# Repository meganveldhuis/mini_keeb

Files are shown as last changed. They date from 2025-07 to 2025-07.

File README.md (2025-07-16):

# Mini Keeb

## Hardware

### Components

- 16 Cherry MX Switches
- 2 rotary encoders
- 1 128x64 OLED (0.96")

### Schematic

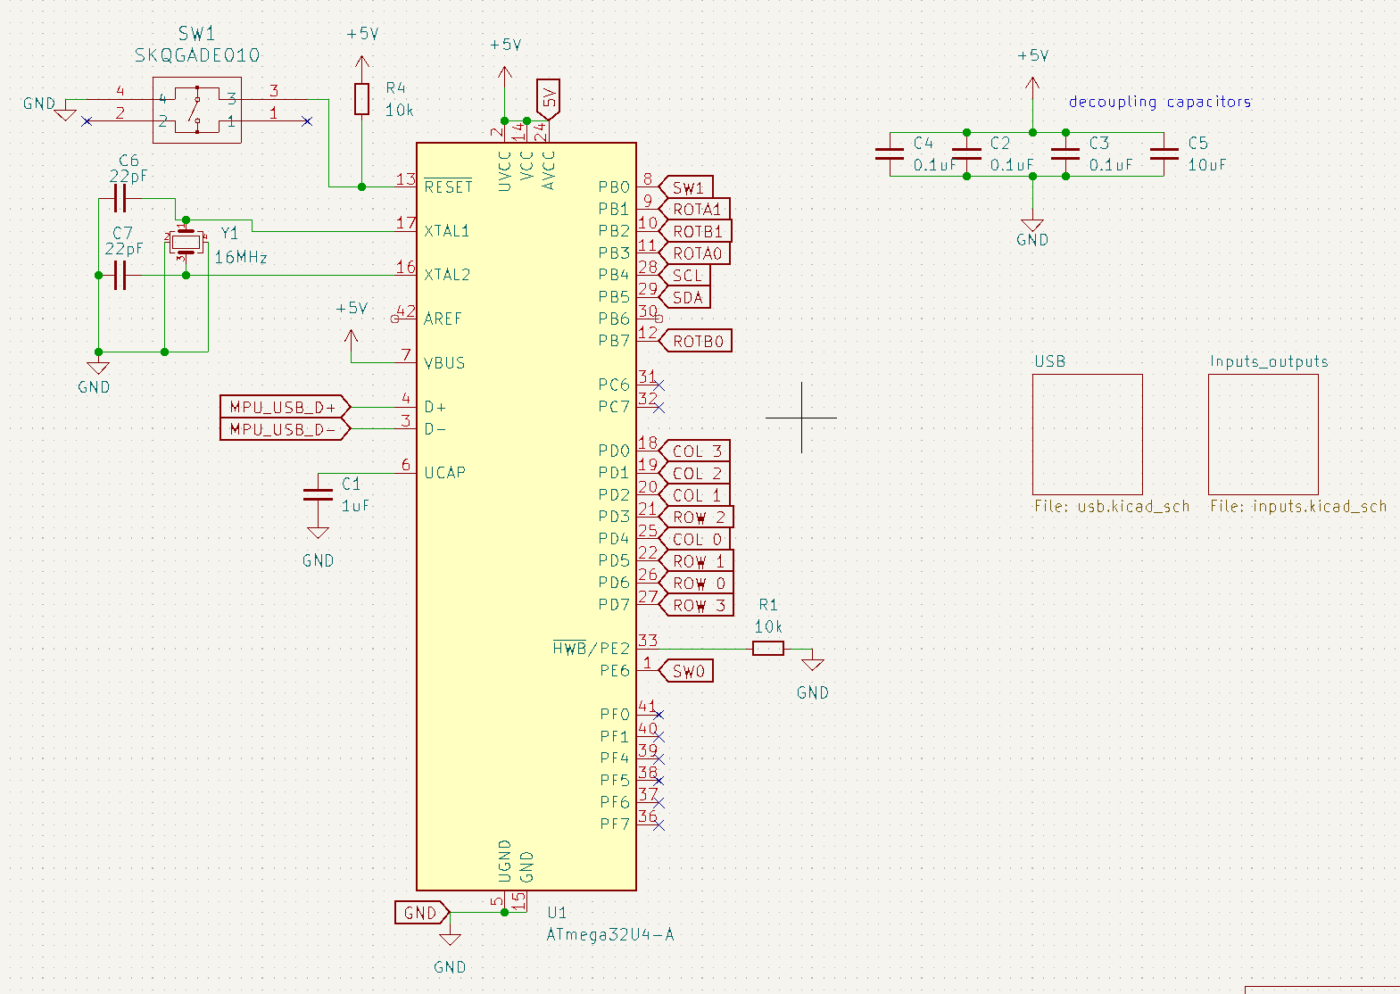
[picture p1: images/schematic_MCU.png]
Schematic of the ATMega32U4 and its connections


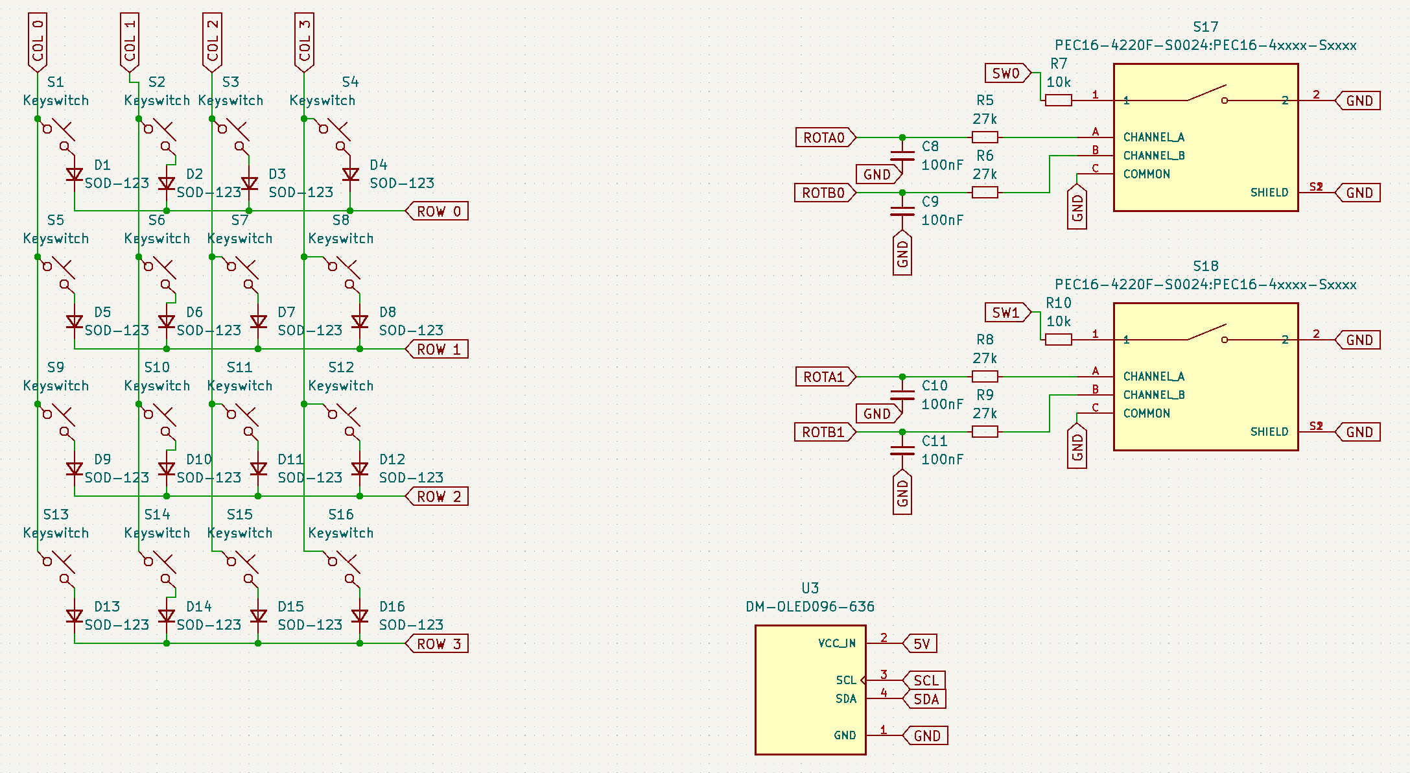
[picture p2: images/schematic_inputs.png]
Schematic of inputs and outputs (switches, rotary encoders, OLED)


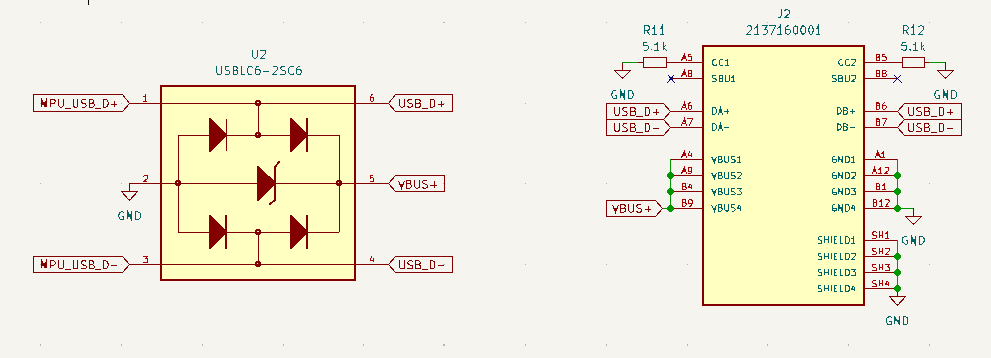
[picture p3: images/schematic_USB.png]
Schematic of USBC connection


### PCB

( slightly outdated screenshots )
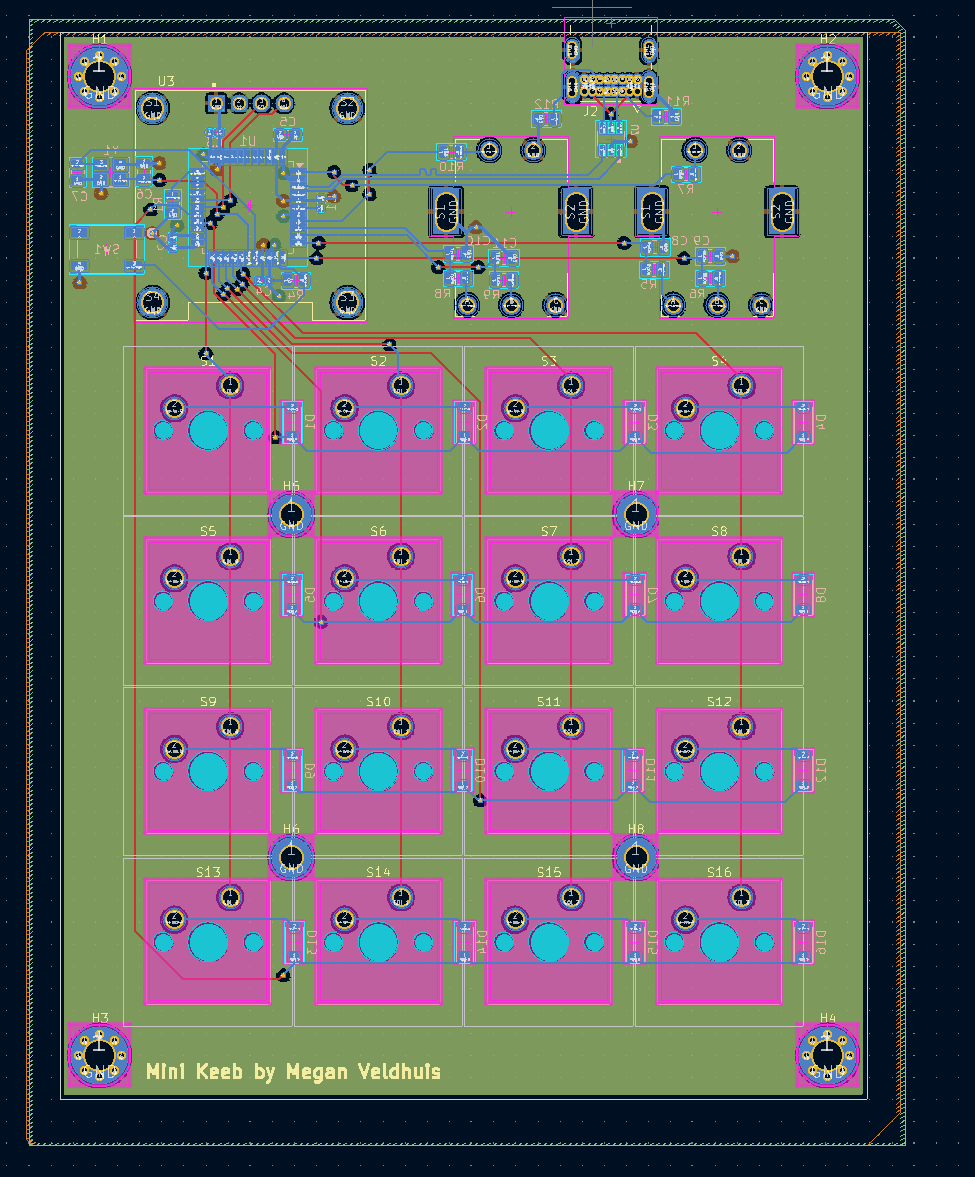
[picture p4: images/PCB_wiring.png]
Screenshot of PCB routing diagram


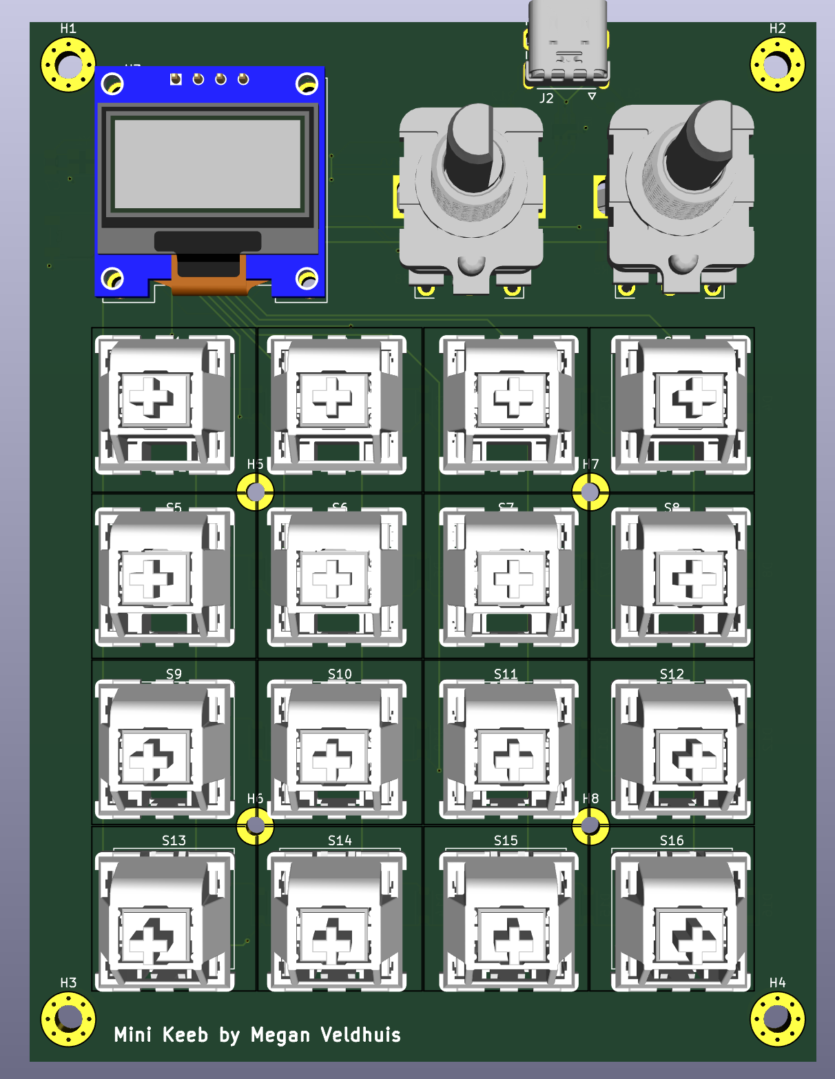
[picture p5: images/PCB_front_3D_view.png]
Screenshot of the front of the PCB, showing the keys, OLED, and rotary encoders


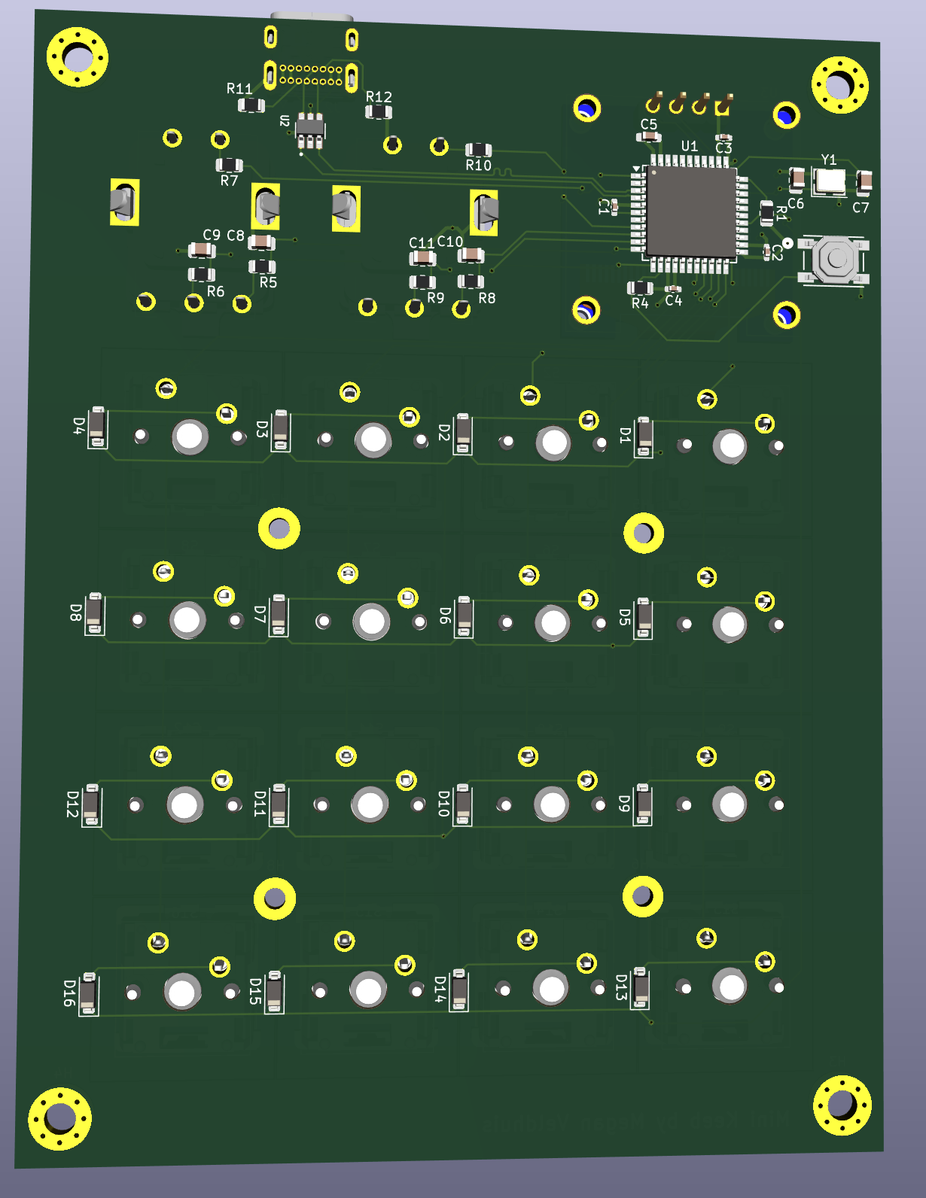
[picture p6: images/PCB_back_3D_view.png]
Screenshot of the back of the PCB


## Software

coming soon

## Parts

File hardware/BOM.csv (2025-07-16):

 |  | PART | AMT |  | PRICE per unit | PART PRICE | LINK
TRUE | D1, D2, D3, D4, D5, D6, D7, D8, D9, D10,D11, D12, D13, D14, D15, D16 | SOD123 Diode | 16 | 160 | $0.15 | $2.40 | https://www.digikey.ca/en/products/detail/diodes-incorporated/BAV21W-7-F/717710
TRUE | S17, S18 | PEC16 rot encoder | 2 | 20 | $3.15 | $6.30 | https://www.digikey.ca/en/products/detail/bourns-inc/PEC16-4220F-S0024/3534239 | https://www.digikey.ca/en/products/detail/bourns-inc/PEC16-4220F-S0012/3780232
TRUE | S1-S16 | MX Switches | 16 | 160 |  | $0.00
TRUE | C1 | 1uF cap (0402) | 1 | 10 | $0.12 | $0.12 | https://www.digikey.ca/en/products/detail/taiyo-yuden/JMK105BJ105KV-F/930583
TRUE | C2, C3, C4 | 0.1uF cap (0402) | 3 | 30 | $0.12 | $0.36 | https://www.digikey.ca/en/products/detail/samsung-electro-mechanics/CL05B104KP5NNNC/3886660
TRUE | C5 | 10uF cap (0603) | 1 | 10 | $0.21 | $0.21 | https://www.digikey.ca/en/products/detail/murata-electronics/GRM21BR61C106KE15K/2546903
TRUE | C6, C7 | 22pF cap (0805) | 2 | 20 | $0.15 | $0.30 | https://www.digikey.ca/en/products/detail/kemet/C0805C220J5GACTU/411112
TRUE | C8, C9, C10, C11 | 100nF cap (0805) | 4 | 40 | $0.47 | $1.88 | https://www.digikey.ca/en/products/detail/vishay-sprague/TMCP1D104MTRF/10107432
TRUE | U3 | OLED 128x64 (0.96") | 1 | 10 | $12.00 | $12.00 | https://www.amazon.ca/128X64-Serial-Display-Module-White/dp/B075H4CSXF?sp_csd=d2lkZ2V0TmFtZT1zcF9hdGY | https://www.digikey.ca/en/products/detail/adafruit-industries-llc/326/5353680
TRUE | R1, R4, R7, R10 | 10k resistor (0805) | 4 | 40 | $0.16 | $0.64 | https://www.digikey.ca/en/products/detail/susumu/RR1220P-103-D/432315
TRUE | R5, R6, R8, R9 | 27k resistor (0805) | 4 | 40 | $0.16 | $0.64 | https://www.digikey.ca/en/products/detail/stackpole-electronics-inc/RMCF0805JT27K0/1757886
FALSE | SW1 | low-profile switch | 1 | 10 | $0.31 | $0.31 | https://www.digikey.ca/en/products/detail/alps-alpine/SKQGADE010/18109115
TRUE | U1 | ATMega32U4-A | 1 | 10 | $8.30 | $8.30 | https://www.digikey.ca/en/products/detail/microchip-technology/ATMEGA32U4-AU/1914602
FALSE | J2 | USB-C connector (Molex-2137160001) | 1 | 10 | $2.12 | $2.12 | https://www.digikey.ca/en/products/detail/molex/2137160001/13662558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
TRUE | Y1 | 16MHz crystal (SMD 3225-4pin) | 1 | 10 | $0.61 | $0.61 | https://www.digikey.ca/en/products/detail/epson/TSX-3225-16-0000MF09Z-AC0/5260850
FALSE | U2 | USBLC6-2SC6 | 1 | 10 | $0.36 | $0.36 | https://www.digikey.ca/en/products/detail/stmicroelectronics/USBLC6-2SC6/1040559
 |  |  |  |  | TOTAL | 34.46

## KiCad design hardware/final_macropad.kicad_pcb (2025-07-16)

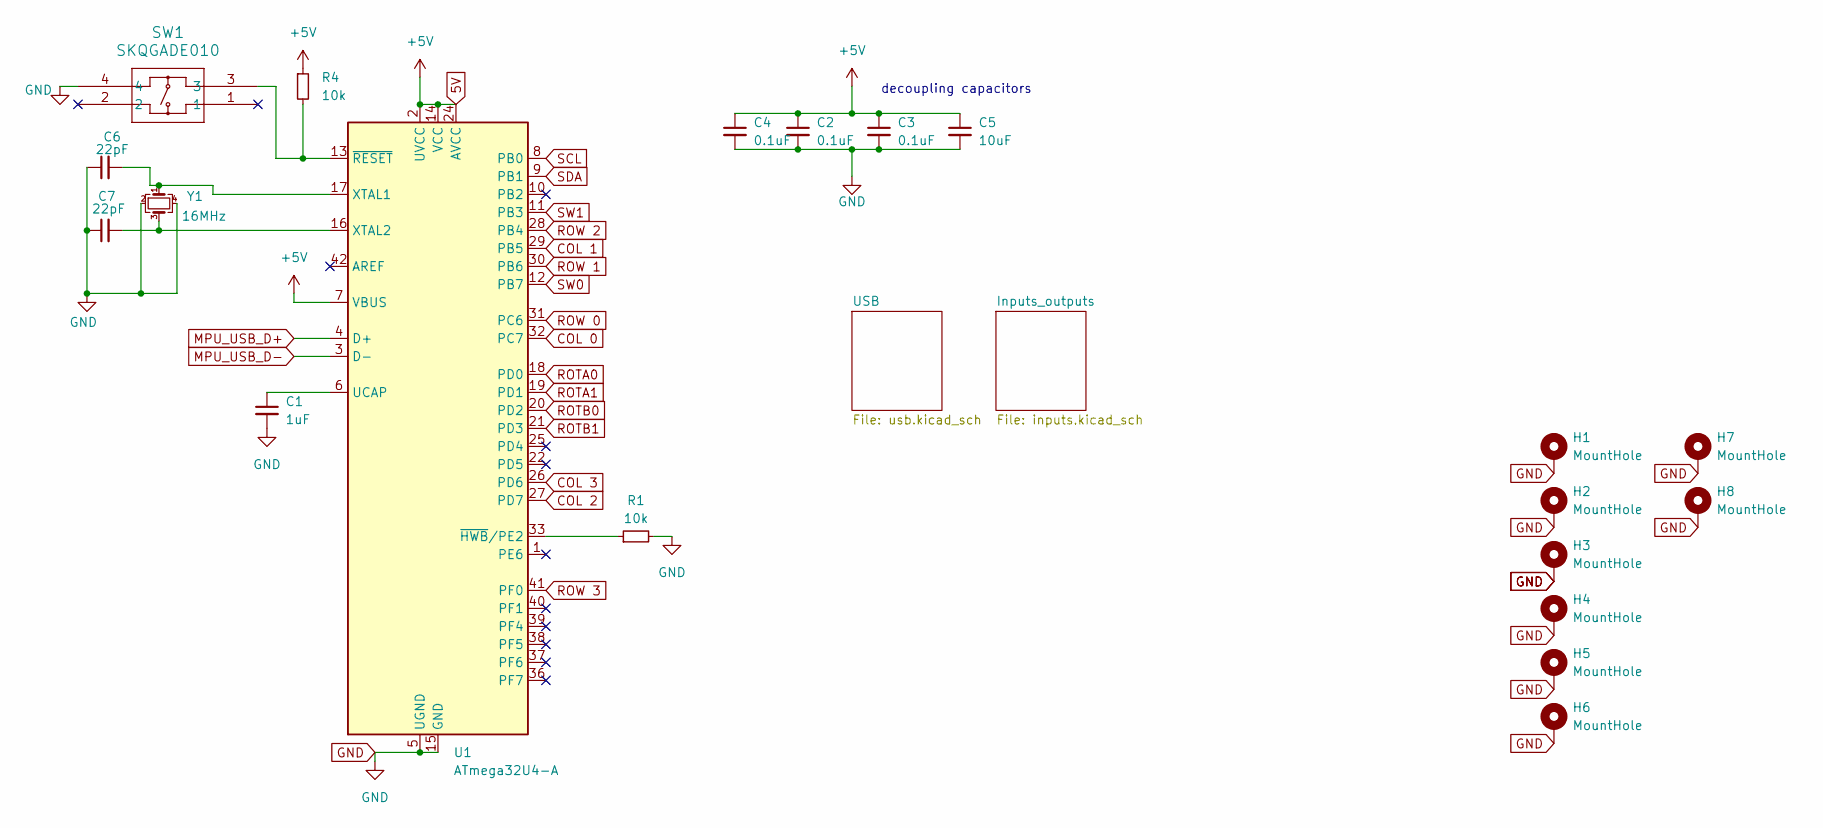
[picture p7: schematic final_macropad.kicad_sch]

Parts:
C1: 1uF; C_0402_1005Metric_Pad0.74x0.62mm_HandSolder
C2, C3, C4: 0.1uF; C_0402_1005Metric_Pad0.74x0.62mm_HandSolder
C5: 10uF; C_0603_1608Metric_Pad1.08x0.95mm_HandSolder
C6, C7: 22pF; C_0805_2012Metric
H1, H2, H3, H4: MountHole; MountingHole_3.2mm_M3_Pad_Via
H5, H6, H7, H8: MountHole; MountingHole_2.2mm_M2_Pad
R1, R4: 10k; R_0805_2012Metric
SW1: SKQGADE010; SKQGADE010_AAL
U1: ATmega32U4-A; TQFP-44_10x10mm_P0.8mm
Y1: 16MHz; Crystal_SMD_3225-4Pin_3.2x2.5mm

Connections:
5V: C2.1, C3.1, C4.1, C5.1, R4.1, U1.2 (UVCC), U1.7 (VBUS), U1.14 (VCC), U1.24 (AVCC), U1.34 (VCC), U1.44 (AVCC); also elsewhere on the board
COL 0: U1.32 (PC7); also elsewhere on the board
COL 1: U1.29 (PB5); also elsewhere on the board
COL 2: U1.27 (PD7); also elsewhere on the board
COL 3: U1.26 (PD6); also elsewhere on the board
GND: C1.2, C2.2, C3.2, C4.2, C5.2, C6.1, C7.1, H1.1, H2.1, H3.1, H4.1, H5.1, H6.1, H7.1, H8.1, R1.2, SW1.4, U1.5 (UGND), U1.15 (GND), U1.23 (GND), U1.35 (GND), U1.43 (GND), Y1.2, Y1.4; also elsewhere on the board
MPU_USB_D+: U1.4 (D+); also elsewhere on the board
MPU_USB_D-: U1.3 (D-); also elsewhere on the board
unnamed: C1.1, U1.6 (UCAP)
unnamed: C6.2, U1.17 (XTAL1), Y1.1
unnamed: C7.2, U1.16 (XTAL2), Y1.3
unnamed: R1.1, U1.33 (~HWB/PE2)
unnamed: R4.2, SW1.3, U1.13 (~RESET)
ROTA0: U1.18 (PD0); also elsewhere on the board
ROTA1: U1.19 (PD1); also elsewhere on the board
ROTB0: U1.20 (PD2); also elsewhere on the board
ROTB1: U1.21 (PD3); also elsewhere on the board
ROW 0: U1.31 (PC6); also elsewhere on the board
ROW 1: U1.30 (PB6); also elsewhere on the board
ROW 2: U1.28 (PB4); also elsewhere on the board
ROW 3: U1.41 (PF0); also elsewhere on the board
SCL: U1.8 (PB0); also elsewhere on the board
SDA: U1.9 (PB1); also elsewhere on the board
SW0: U1.12 (PB7); also elsewhere on the board
SW1: U1.11 (PB3); also elsewhere on the board

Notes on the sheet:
decoupling capacitors

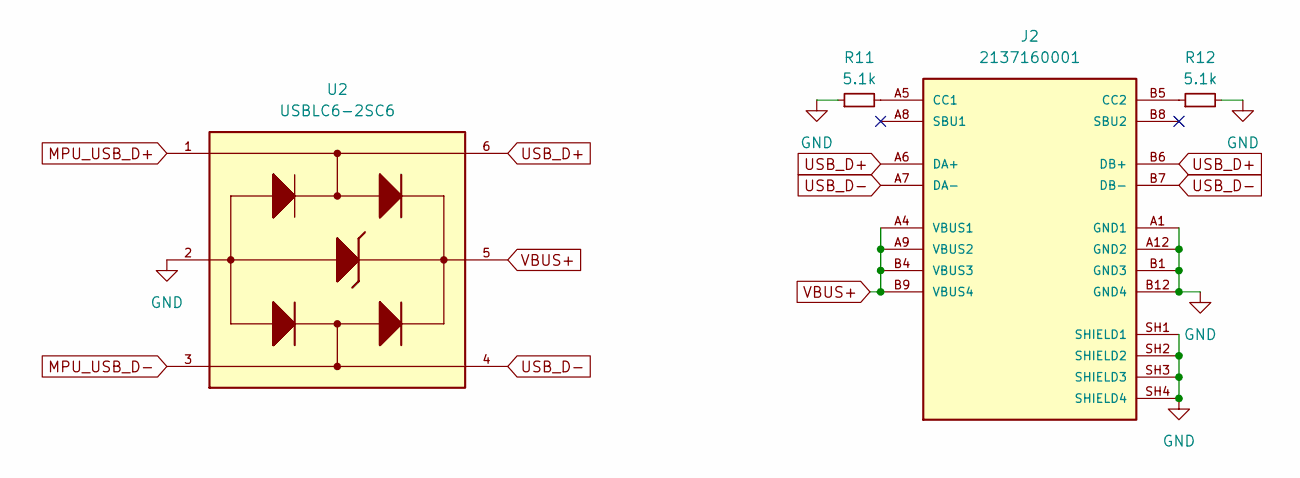
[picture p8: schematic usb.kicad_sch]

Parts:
J2: 2137160001; MOLEX_2137160001; PARTREV B
R11, R12: 5.1k; R_0805_2012Metric
U2: USBLC6-2SC6; SOT95P280X145-6N

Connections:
GND: J2.A1 (GND1), J2.A12 (GND2), J2.B1 (GND3), J2.B12 (GND4), J2.SH1 (SHIELD1), J2.SH2 (SHIELD2), J2.SH3 (SHIELD3), J2.SH4 (SHIELD4), R11.1, R12.2, U2.2; also elsewhere on the board
MPU_USB_D+: U2.1; also elsewhere on the board
MPU_USB_D-: U2.3; also elsewhere on the board
unnamed: J2.A5 (CC1), R11.2
unnamed: J2.B5 (CC2), R12.1
USB_D+: J2.A6 (DA+), J2.B6 (DB+), U2.6
USB_D-: J2.A7 (DA-), J2.B7 (DB-), U2.4
VBUS+: J2.A4 (VBUS1), J2.A9 (VBUS2), J2.B4 (VBUS3), J2.B9 (VBUS4), U2.5

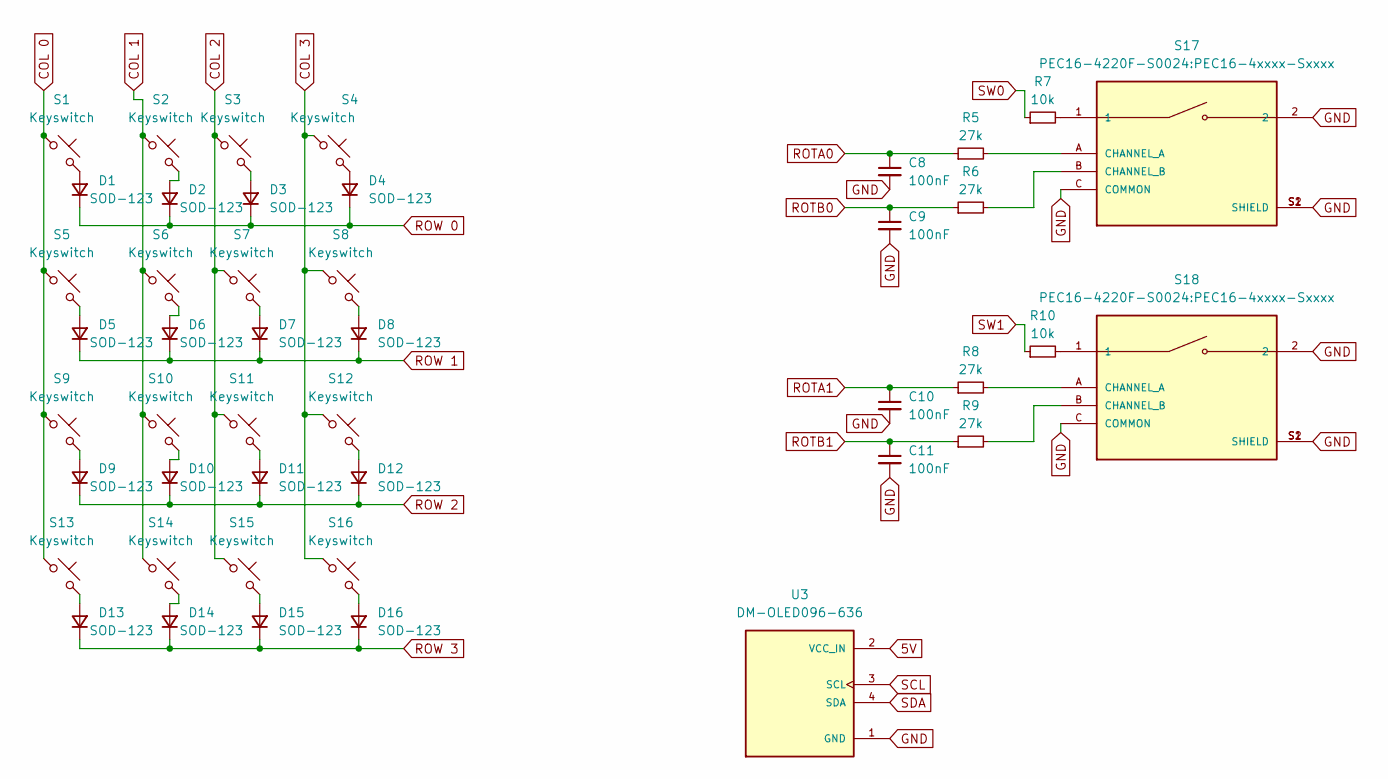
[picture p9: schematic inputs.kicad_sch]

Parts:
C8, C9, C10, C11: 100nF; C_0805_2012Metric
D1, D2, D3, D4, D5, D6, D7, D8, D9, D10, D11, D12, D13, D14, D15, D16: SOD-123; D_SOD-123
R5, R6, R8, R9: 27k; R_0805_2012Metric
R7, R10: 10k; R_0805_2012Metric
S1, S2, S3, S4, S5, S6, S7, S8, S9, S10, S11, S12, S13, S14, S15, S16: Keyswitch; SW_Cherry_MX_1.00u_PCB
S17, S18: PEC16-4220F-S0024:PEC16-4xxxx-Sxxxx; PEC16-4xxxx-Sxxxx; PARTREV 07/21
U3: DM-OLED096-636; MODULE_DM-OLED096-636; PARTREV 2018-09-10

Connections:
5V: U3.2 (VCC_IN); also elsewhere on the board
COL 0: S1.1, S5.1, S9.1, S13.1; also elsewhere on the board
COL 1: S2.1, S6.1, S10.1, S14.1; also elsewhere on the board
COL 2: S3.1, S7.1, S11.1, S15.1; also elsewhere on the board
COL 3: S4.1, S8.1, S12.1, S16.1; also elsewhere on the board
GND: C8.2, C9.2, C10.2, C11.2, S17.2, S17.C (COMMON), S17.S1 (SHIELD), S17.S2 (SHIELD), S18.2, S18.C (COMMON), S18.S1 (SHIELD), S18.S2 (SHIELD), U3.1 (GND), U3.S1, U3.S2, U3.S3, U3.S4; also elsewhere on the board
unnamed: D1.2 (A), S1.2
unnamed: D2.2 (A), S2.2
unnamed: D3.2 (A), S3.2
unnamed: D4.2 (A), S4.2
unnamed: D5.2 (A), S5.2
unnamed: D6.2 (A), S6.2
unnamed: D7.2 (A), S7.2
unnamed: D8.2 (A), S8.2
unnamed: D9.2 (A), S9.2
unnamed: D10.2 (A), S10.2
unnamed: D11.2 (A), S11.2
unnamed: D12.2 (A), S12.2
unnamed: D13.2 (A), S13.2
unnamed: D14.2 (A), S14.2
unnamed: D15.2 (A), S15.2
unnamed: D16.2 (A), S16.2
unnamed: R7.2, S17.1
unnamed: R10.2, S18.1
unnamed: R5.2, S17.A (CHANNEL_A)
unnamed: R6.2, S17.B (CHANNEL_B)
unnamed: R8.2, S18.A (CHANNEL_A)
unnamed: R9.2, S18.B (CHANNEL_B)
ROTA0: C8.1, R5.1; also elsewhere on the board
ROTA1: C10.1, R8.1; also elsewhere on the board
ROTB0: C9.1, R6.1; also elsewhere on the board
ROTB1: C11.1, R9.1; also elsewhere on the board
ROW 0: D1.1 (K), D2.1 (K), D3.1 (K), D4.1 (K); also elsewhere on the board
ROW 1: D5.1 (K), D6.1 (K), D7.1 (K), D8.1 (K); also elsewhere on the board
ROW 2: D9.1 (K), D10.1 (K), D11.1 (K), D12.1 (K); also elsewhere on the board
ROW 3: D13.1 (K), D14.1 (K), D15.1 (K), D16.1 (K); also elsewhere on the board
SCL: U3.3 (SCL); also elsewhere on the board
SDA: U3.4 (SDA); also elsewhere on the board
SW0: R7.1; also elsewhere on the board
SW1: R10.1; also elsewhere on the board

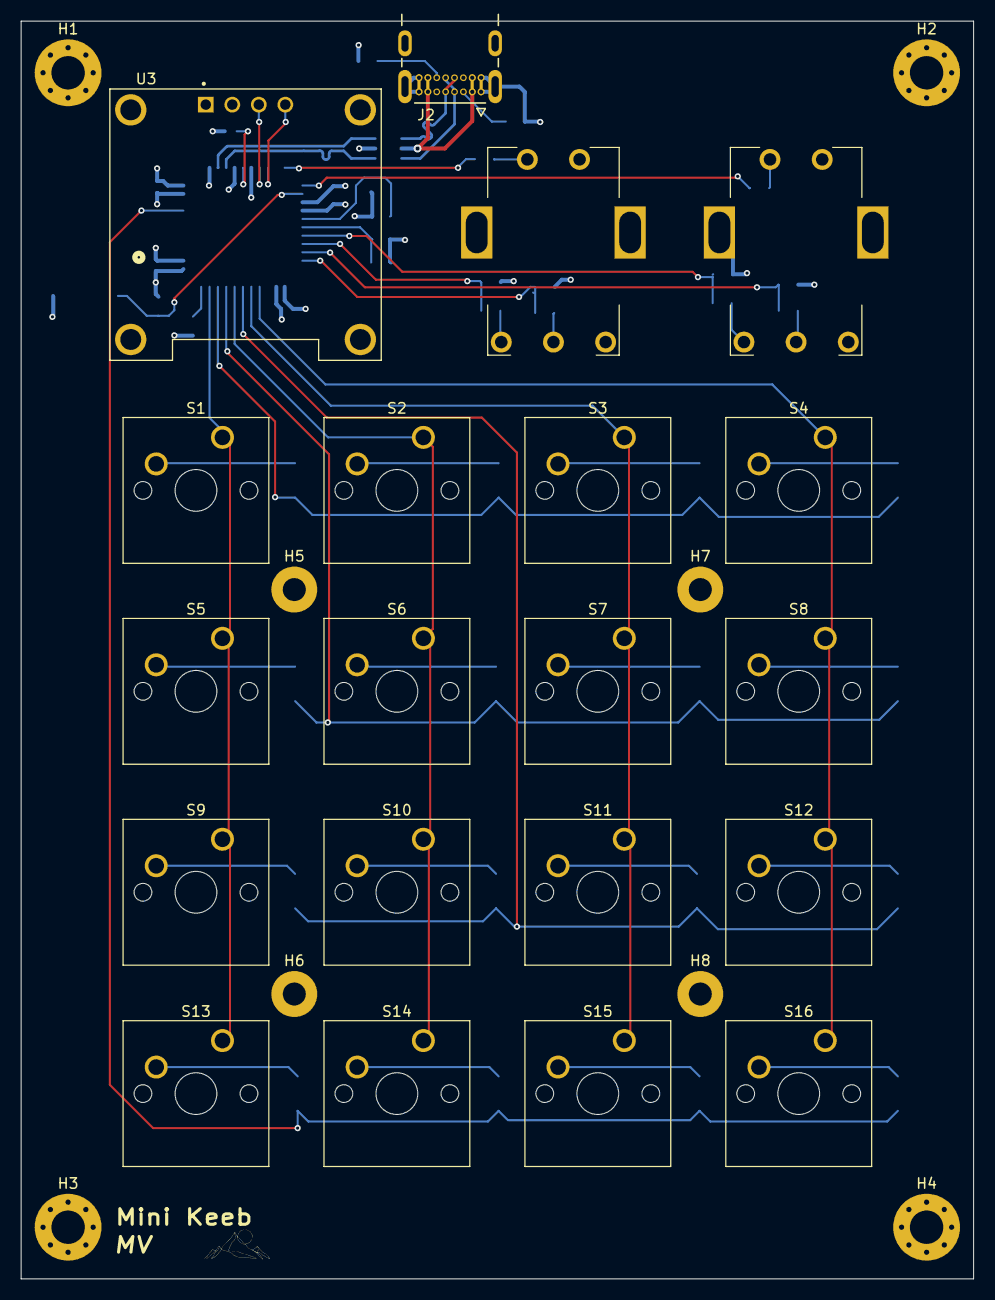
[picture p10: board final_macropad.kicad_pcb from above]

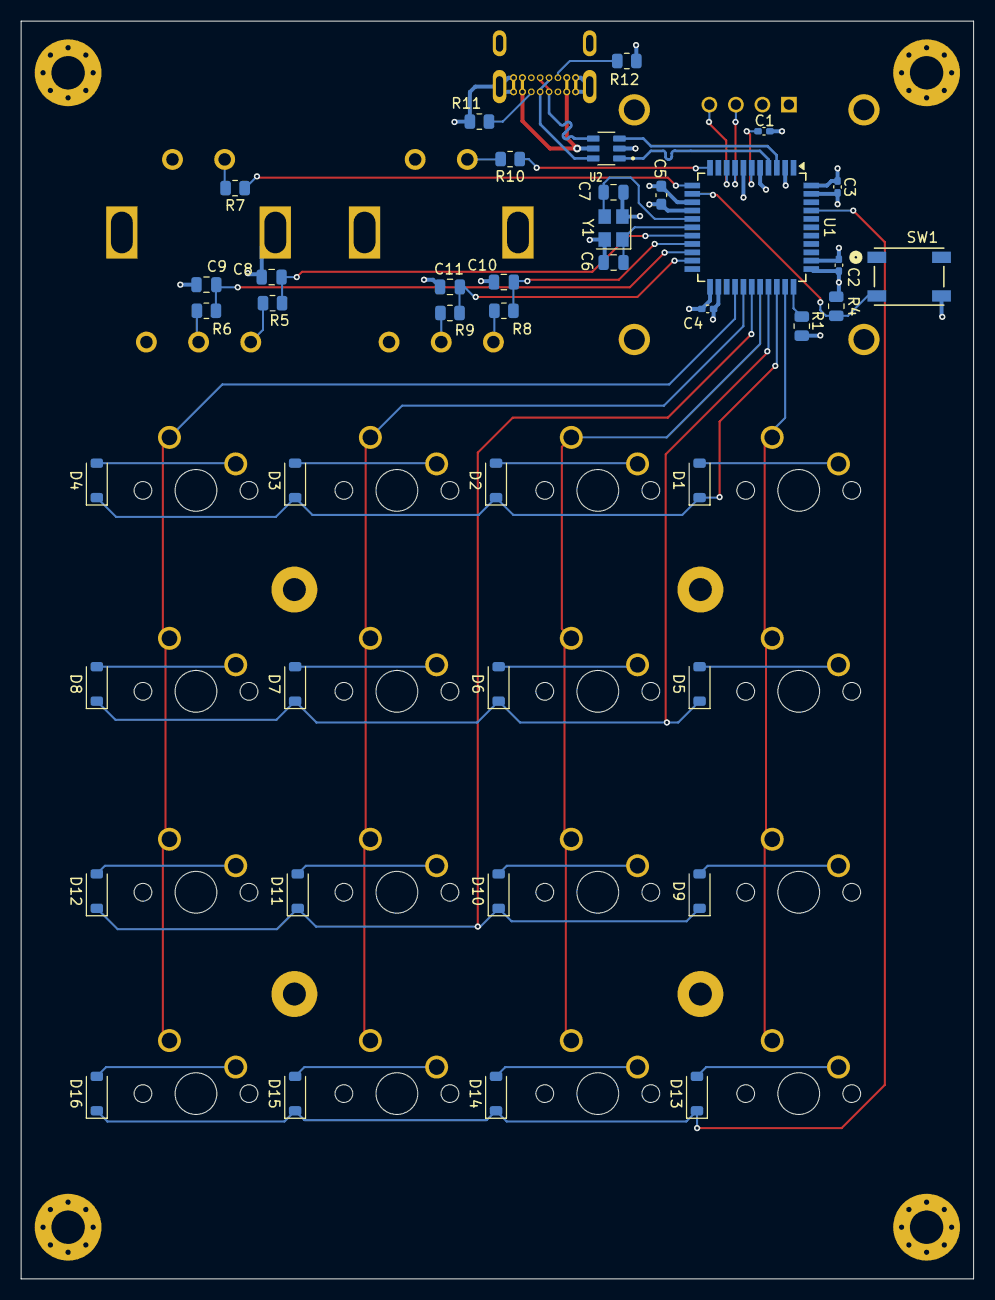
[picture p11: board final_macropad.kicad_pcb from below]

Board: 4 copper layers, 91.2 x 120.5 mm, 69 parts (41 on the bottom side), 52 nets.

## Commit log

2025-03-04 add schematic and unrouted pcb
    [practice_keyboard.kicad_pcb, practice_keyboard.kicad_sch]
2025-05-20 updated PCB to be most recent edition
    [final_macropad.csv, final_macropad.kicad_pcb, final_macropad.kicad_sch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]
2025-05-24 organize schematic and add USB-C and surge protector
    [final_macropad.kicad_pcb, final_macropad.kicad_sch, inputs.kicad_sch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]
2025-05-25 remove old diodes
    [final_macropad.kicad_pcb]
2025-05-26 fix switches to be correct order and move diodes
    [final_macropad.kicad_pcb, final_macropad.kicad_sch, inputs.kicad_sch]
2025-05-26 route USBC connector
    [final_macropad.kicad_pcb, inputs.kicad_sch, usb.kicad_sch]
2025-05-28 route USB and rotary encoder
    [final_macropad.kicad_pcb]
2025-05-28 update PCB routing
    [final_macropad.kicad_pcb]
2025-05-29 route all switches
    [final_macropad.kicad_pcb]
2025-05-29 check DRC
    [final_macropad.kicad_pcb]
2025-05-31 update BOM
    [BOM.csv, final_macropad.csv]
2025-05-31 update BOM and reset button footprint
    [BOM.csv, final_macropad.kicad_pcb, final_macropad.kicad_sch]
2025-05-31 update BOM and add to silkscreen
    [final_macropad.kicad_pcb]
2025-06-08 rotate MCU, route reset button, crystal, and OLED
    [final_macropad.kicad_sch]
2025-06-08 reroute decoupling capacitors
    [final_macropad.kicad_pcb]
2025-06-10 Finish rerouting
    [final_macropad.kicad_pcb, final_macropad.kicad_sch]
2025-06-10 increase trace width from USBC connector
    [final_macropad.kicad_pcb]
2025-06-10 move trace away from through-hole
    [final_macropad.kicad_pcb]
2025-06-13 build gerber files
    [BOM.csv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]
2025-06-27 update pcb schematic
